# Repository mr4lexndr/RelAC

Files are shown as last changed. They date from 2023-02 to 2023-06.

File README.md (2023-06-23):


[][cc-by-nc-sa]

This work is licensed under a
[Creative Commons Attribution-NonCommercial-ShareAlike 4.0 International License][cc-by-nc-sa].

[][cc-by-nc-sa]



[cc-by-nc-sa]: http://creativecommons.org/licenses/by-nc-sa/4.0/
[cc-by-nc-sa-image]: https://licensebuttons.net/l/by-nc-sa/4.0/88x31.png
[cc-by-nc-sa-shield]: https://img.shields.io/badge/License-CC%20BY--NC--SA%204.0-lightgrey.svg
# RelAC

HomeKit 2-channel Relay module with mains Switch Input based on the [HomeSpan](https://github.com/HomeSpan/HomeSpan) library. It is mainly intended to be used with mains voltage appliances controlled in parallel with the Home app and physical switch. It could be hidden e.g. behind a wall light switch.

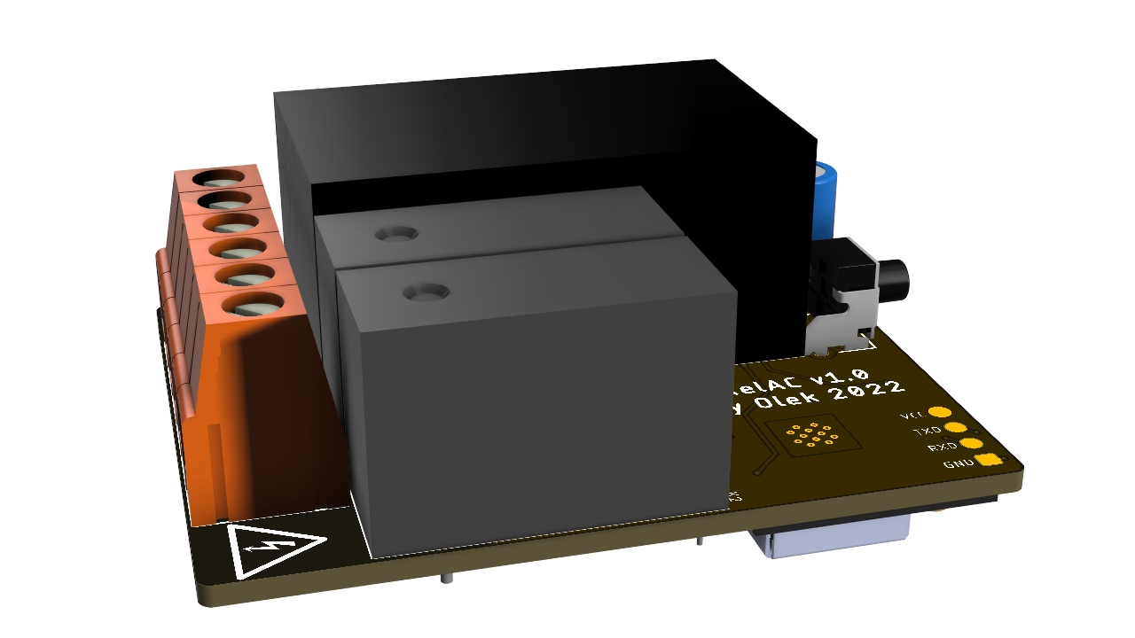
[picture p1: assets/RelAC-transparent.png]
RelAC


## Main Features
- Mains Supply 100-240 Vac
- Status LED and Control push button for easy configuration
- 2 latching relays for low power consumption and thermal emmisions
- 2 live inputs
- Small form factor to be hidden behind the wall light switch.
- Can be configured as single channel device to save cost
  
### Switching Relays
- High quality, low wear Panasonic ADW1203HLW  
- Switching Capacity 16A @ 277V AC  
- Contact material AgSnO2 to minimise arcing  

## User Integration with HomeSpan
Status LED and Control Button are attached to deafault pins for most of the boards. S1 Button is also used as boot button during programming
- LED `GPIO2`
- Button `GPIO0`

## Pinout
Pin assignment for relays and switch inputs. For single channel version only `RELAY 1` and `SWITCH 2` are used.

- RELAY 1
  -  on `GPIO27`
  - off `GPIO26`
- RELAY 2 
  - on `GPIO33`
  - off `GPIO32`
- MAINS INPUT
  - switch 1 `GPIO16`
  - switch 2 `GPIO13`

## User Guide
The setup procedure and configuration can be found [here](https://github.com/HomeSpan/HomeSpan/blob/master/docs/UserGuide.md)

## To Do

- [ ] finish 3D printed case
- [ ] reduce footprint with next revision
- [ ] change layout of programming pins and add RTS support

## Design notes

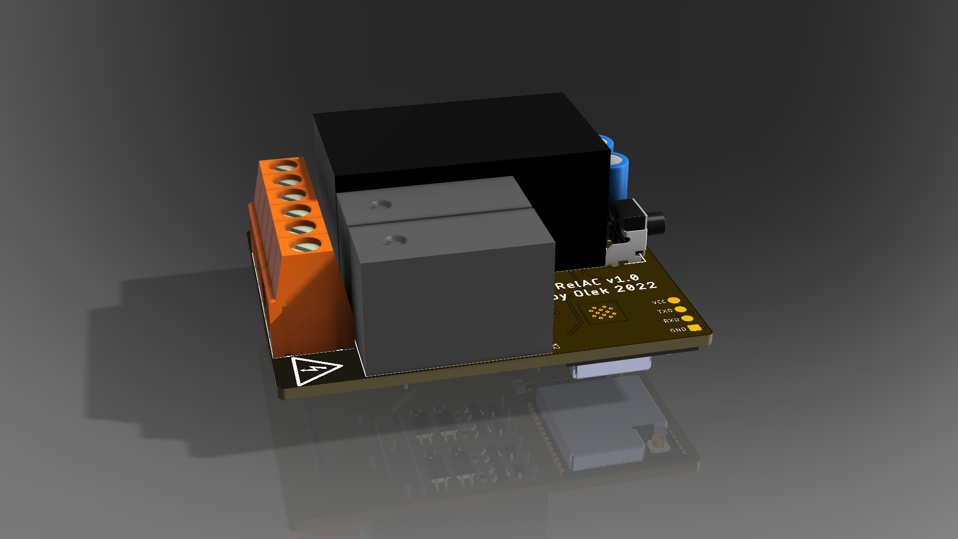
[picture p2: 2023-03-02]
assets/RelAC-board.png

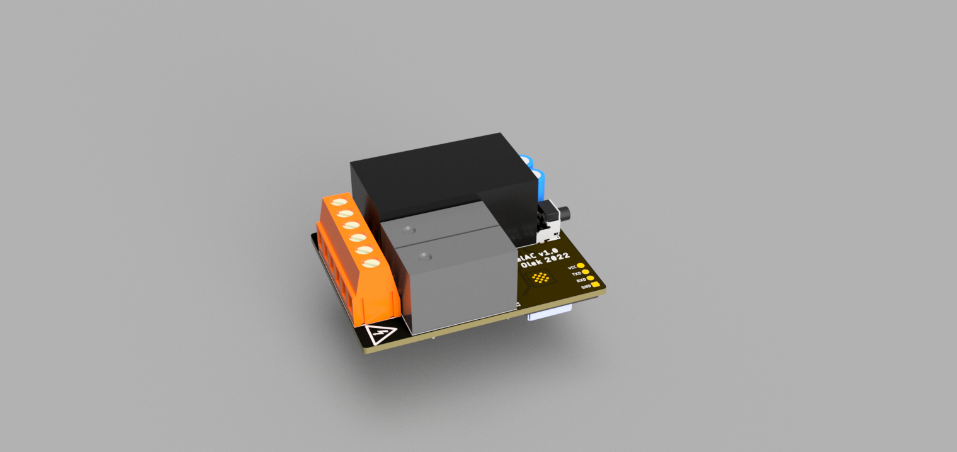
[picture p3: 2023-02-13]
assets/RelAC-top.png

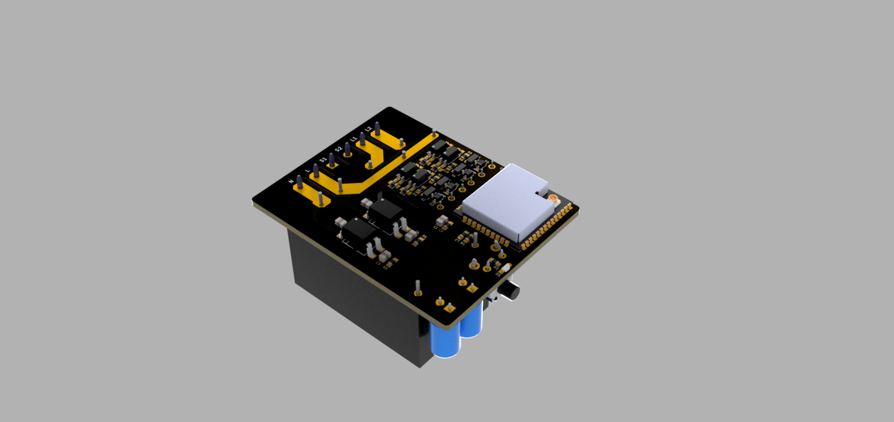
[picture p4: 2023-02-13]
assets/RelAC-bottom.png

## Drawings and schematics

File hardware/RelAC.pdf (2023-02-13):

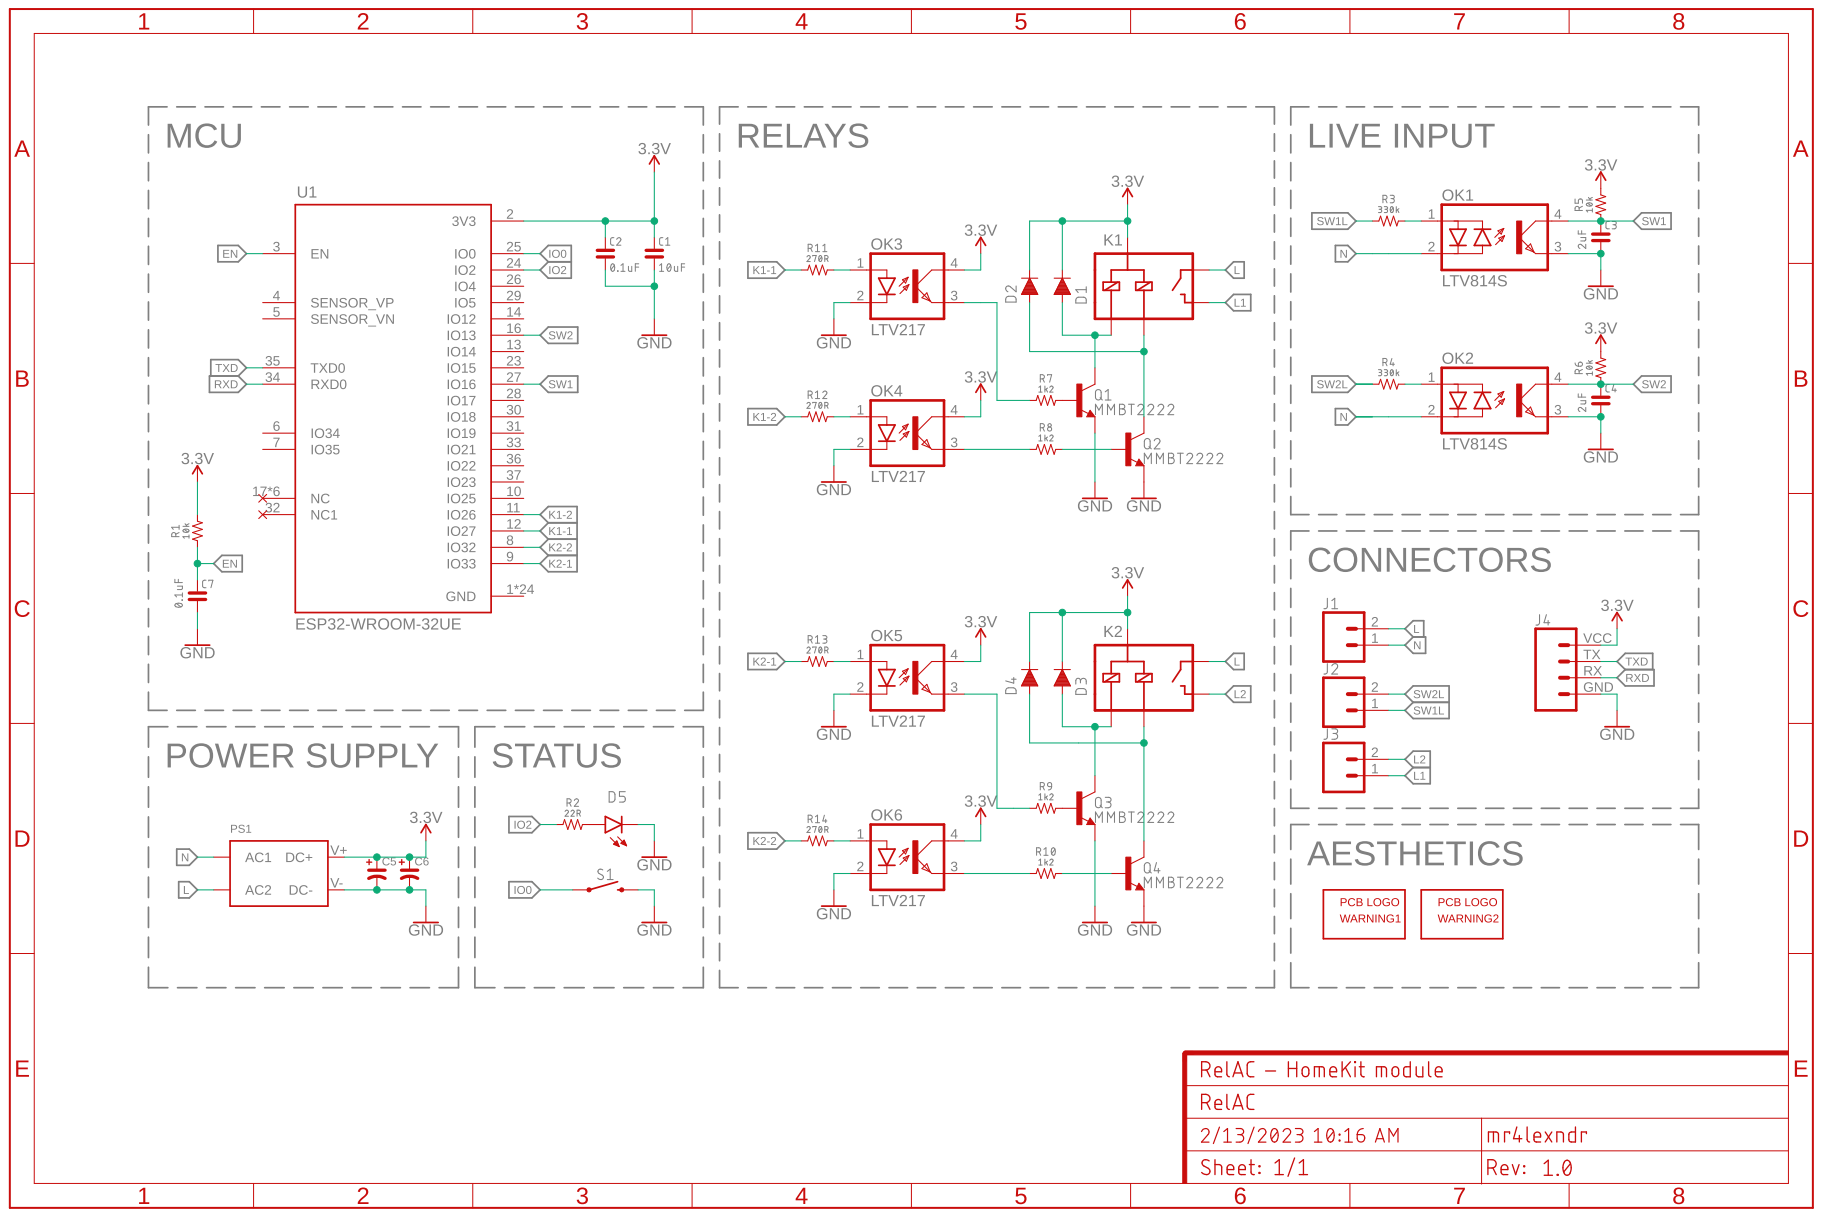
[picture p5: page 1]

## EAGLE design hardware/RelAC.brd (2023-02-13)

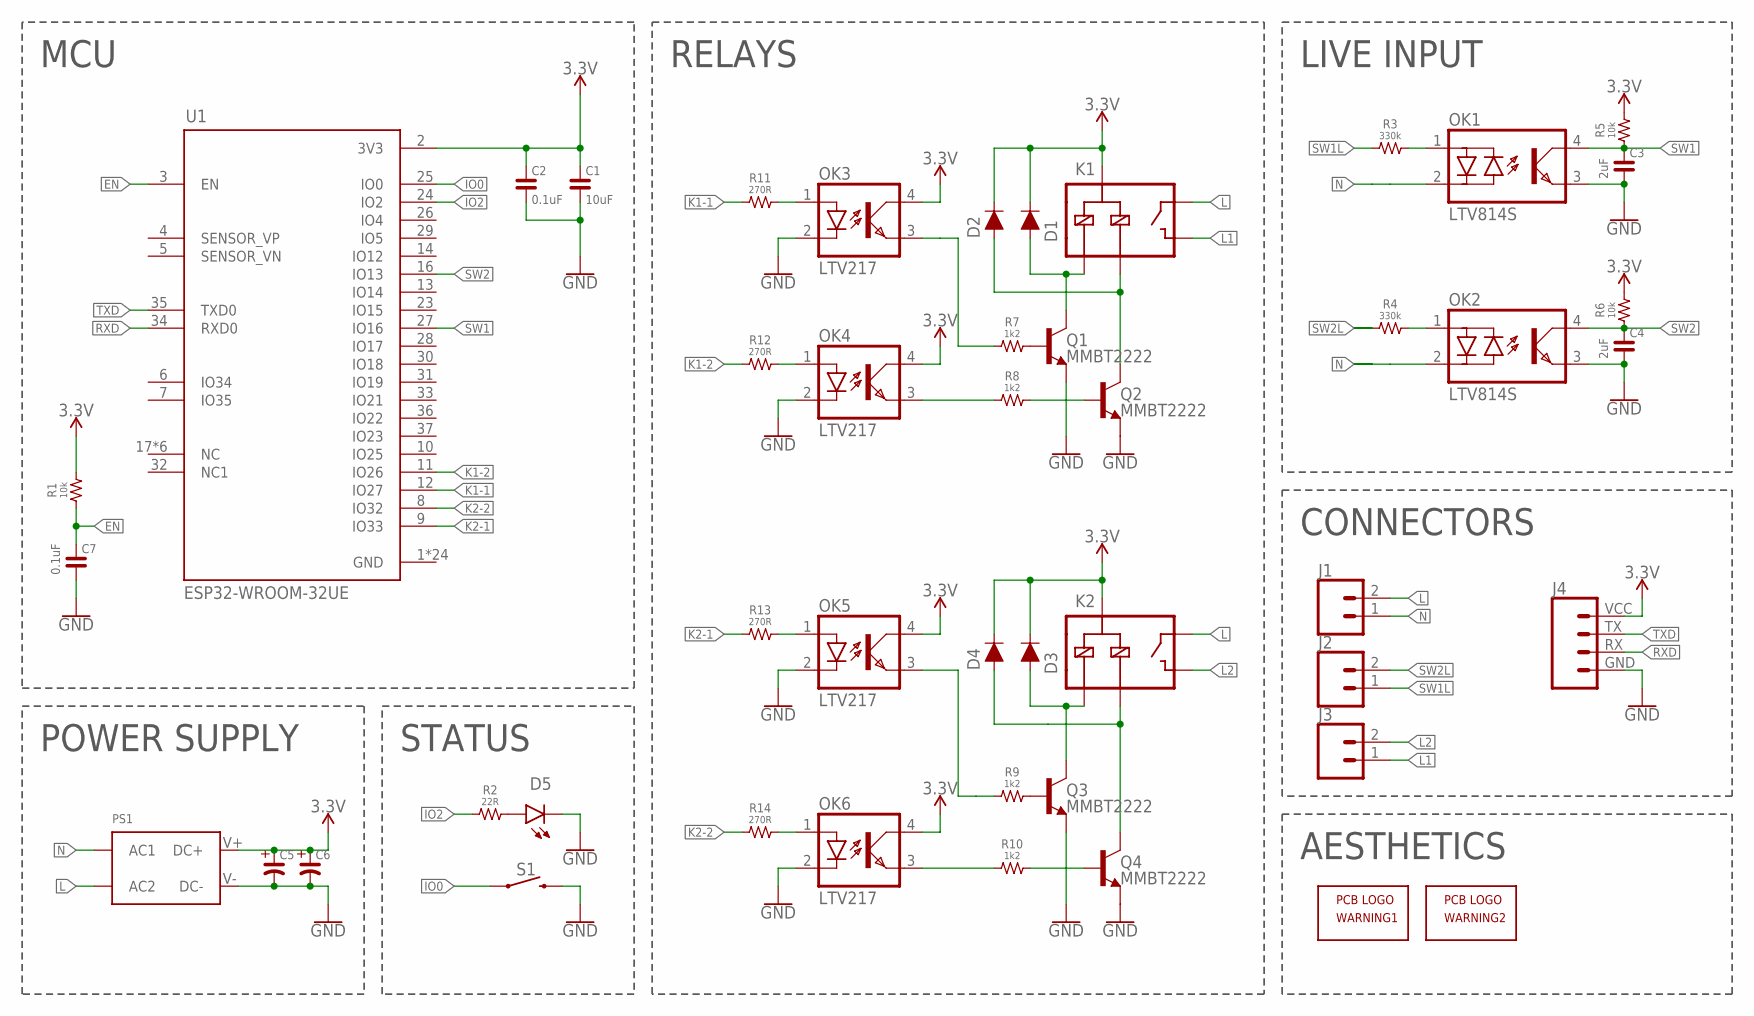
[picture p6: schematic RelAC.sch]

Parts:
C1: 10uF; 0805
C2, C7: 0.1uF; 0603
C3, C4: 2uF; 0805
C5, C6: CAP-POLAR-THT_2.5MM-W; CPOL-RADIAL-2.5MM-6.5MM
D1, D2, D3, D4: DIODE-SOD323; SOD-323
D5: LED-ANGLE-2MM
J1, J2, J3: CONN_02-5MM-SCREWTERMINAL; SCREWTERMINAL-5MM-2-DIBO
J4: CONN_04-UART-SMD; UART
K1, K2: RELAY-SPST-LATCHING; RELAY-PANASONIC-ADW1203HLW
OK1, OK2: LTV814S; DIL4-SMD-SMALL
OK3, OK4, OK5, OK6: LTV217; MINI-FLAT-4
PS1: POWER-SUPPLY-HI-LINK-5W; HI-LINK-POWER-SUPPLY
Q1, Q2, Q3, Q4: MMBT2222; SOT23-3
R1, R5, R6: 10k; 0603
R2: 22R; 0603
R3, R4: 330k; 0805
R7, R8, R9, R10: 1k2; 0603
R11, R12, R13, R14: 270R; 0603
S1: MOMENTARY-SWITCH-SPST-PTH-RIGHT-ANGLE-KIT; TACTILE_SWITCH_PTH_RIGHT_ANGLE_KIT
U1: ESP32-WROOM-32UE; MODULE_ESP32-WROOM-32UE(M113EH6400UH3Q0)
WARNING1, WARNING2: PCB-GRAPHICS-HIGH-VOLTAGE; HIGH-VOLTAGE

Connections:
3.3V: C1.2, C2.2, C5.+, C6.+, D1.C, D2.C, D3.C, D4.C, J4.VCC (4), K1.COILM (COIL-COM), K2.COILM (COIL-COM), OK3.4 (COL), OK4.4 (COL), OK5.4 (COL), OK6.4 (COL), PS1.V+ (DC+), R1.2, R5.2, R6.2, U1.2 (3V3)
EN: C7.2, R1.1, U1.3 (EN)
GND: C1.1, C2.1, C3.1, C4.1, C5.-, C6.-, C7.1, D5.C, J4.GND (1), OK1.3 (EMIT), OK2.3 (EMIT), OK3.2 (C), OK4.2 (C), OK5.2 (C), OK6.2 (C), PS1.V- (DC-), Q1.2 (E), Q2.2 (E), Q3.2 (E), Q4.2 (E), S1.2, U1.1 (GND), U1.15 (GND), U1.38 (GND), U1.39_1 (GND), U1.39_2 (GND), U1.39_3 (GND), U1.39_4 (GND), U1.39_5 (GND), U1.39_6 (GND), U1.39_7 (GND), U1.39_8 (GND), U1.39_9 (GND), U1.39_10 (GND), U1.39_11 (GND), U1.39_12 (GND), U1.39_13 (GND), U1.39_14 (GND), U1.39_15 (GND), U1.39_16 (GND), U1.39_17 (GND), U1.39_18 (GND), U1.39_19 (GND), U1.39_20 (GND), U1.39_21 (GND)
IO0: S1.1, U1.25 (IO0)
IO2: R2.1, U1.24 (IO2)
K1-1: R11.1, U1.12 (IO27)
K1-2: R12.1, U1.11 (IO26)
K2-1: R13.1, U1.9 (IO33)
K2-2: R14.1, U1.8 (IO32)
L: J1.2, K1.POLE, K2.POLE, PS1.AC2
L1: J3.1, K1.NO
L2: J3.2, K2.NO
N: J1.1, OK1.2 (C), OK2.2 (C), PS1.AC1
unnamed: D2.A, K1.COIL2, Q2.3 (C)
unnamed: D1.A, K1.COIL1, Q1.3 (C)
unnamed: OK1.1 (A), R3.2
unnamed: D5.A, R2.2
unnamed: OK2.1 (A), R4.2
unnamed: Q1.1 (B), R7.2
unnamed: Q2.1 (B), R8.2
unnamed: OK3.3 (EMIT), R7.1
unnamed: OK4.3 (EMIT), R8.1
unnamed: D3.A, K2.COIL1, Q3.3 (C)
unnamed: D4.A, K2.COIL2, Q4.3 (C)
unnamed: Q3.1 (B), R9.2
unnamed: Q4.1 (B), R10.2
unnamed: OK6.3 (EMIT), R10.1
unnamed: OK5.3 (EMIT), R9.1
unnamed: OK6.1 (A), R14.2
unnamed: OK5.1 (A), R13.2
unnamed: OK4.1 (A), R12.2
unnamed: OK3.1 (A), R11.2
RXD: J4.RX (2), U1.34 (RXD0)
SW1: C3.2, OK1.4 (COL), R5.1, U1.27 (IO16)
SW1L: J2.1, R3.1
SW2: C4.2, OK2.4 (COL), R6.1, U1.16 (IO13)
SW2L: J2.2, R4.1
TXD: J4.TX (3), U1.35 (TXD0)

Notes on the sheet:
MCU
RELAYS
LIVE INPUT
STATUS
POWER SUPPLY
CONNECTORS
AESTHETICS

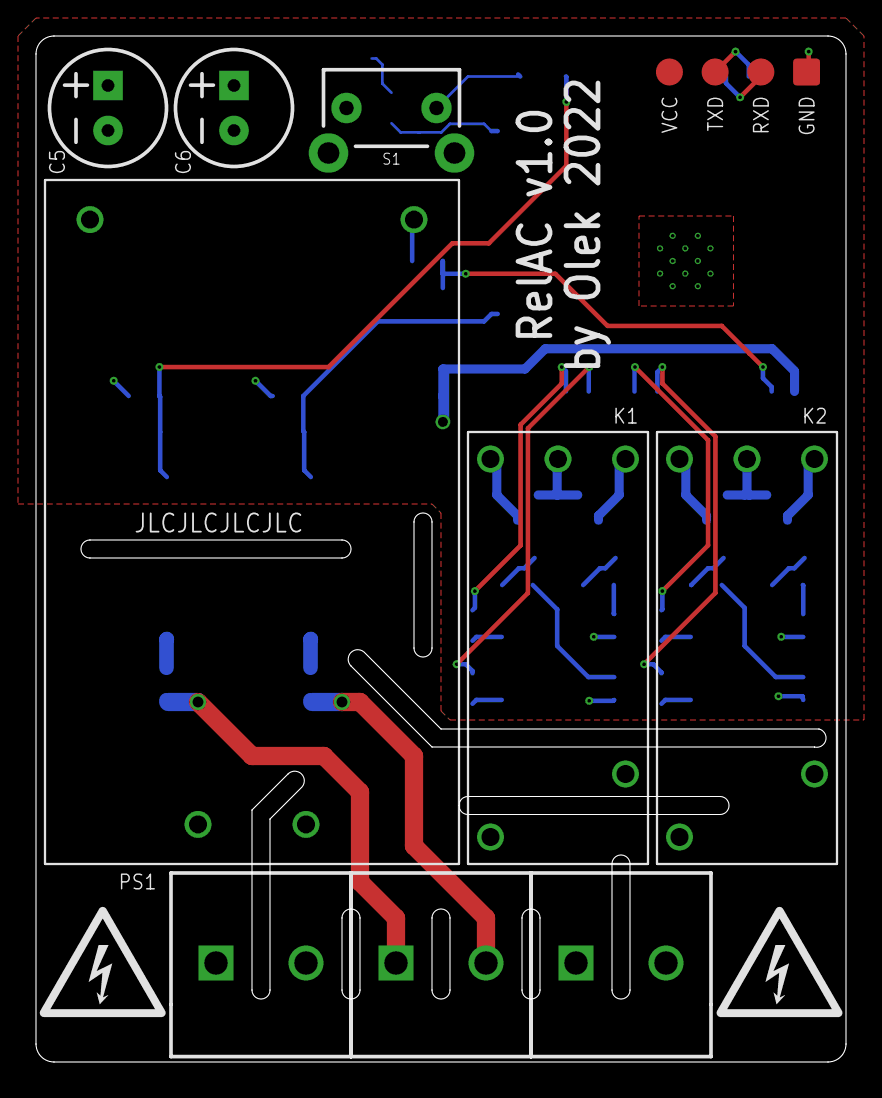
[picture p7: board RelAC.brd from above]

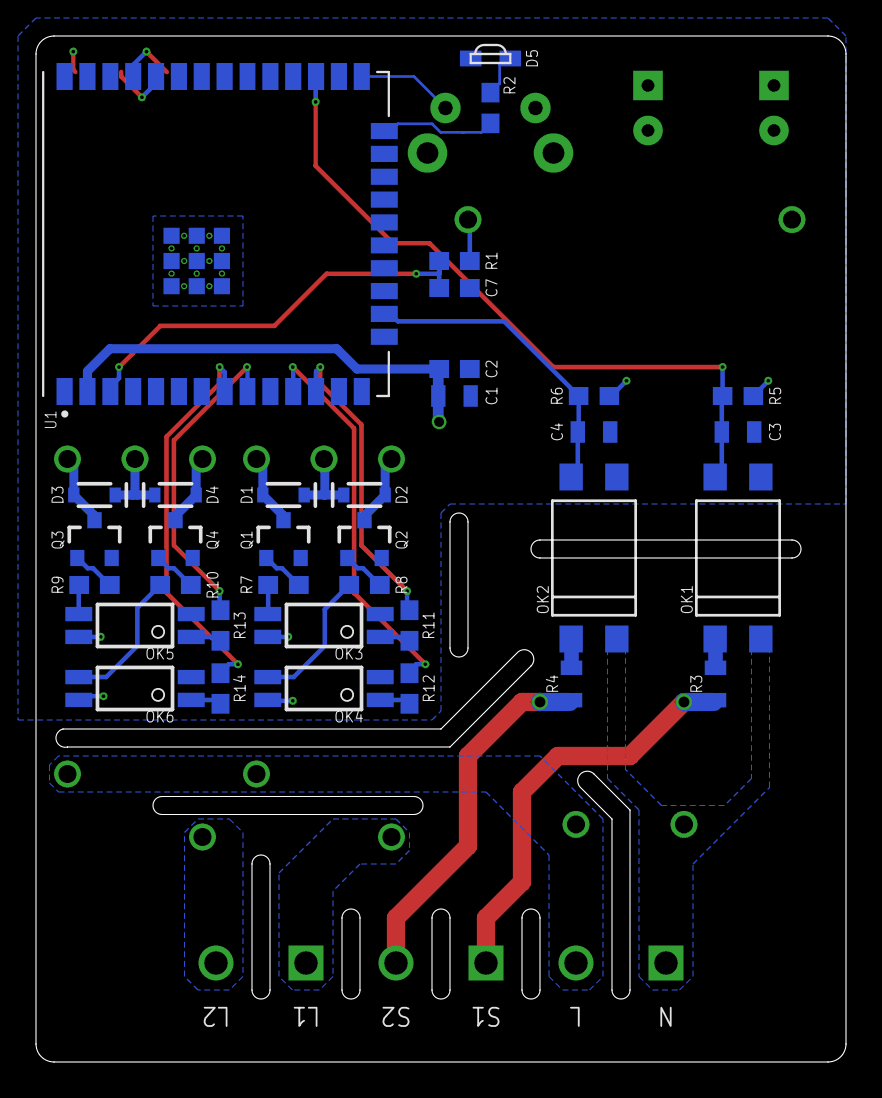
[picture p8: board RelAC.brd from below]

Board: 2 copper layers, 45.0 x 57.0 mm, 47 parts (35 on the bottom side), 38 nets.

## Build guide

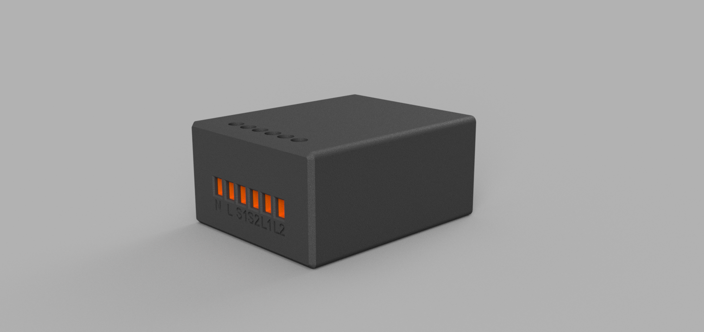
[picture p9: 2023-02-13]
assets/RelAC-dual-assembly.png

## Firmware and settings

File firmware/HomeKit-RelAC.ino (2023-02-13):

////////////////////////////////////////////////////////////
//                                                        //
//      RelAC: a HomeKit dual channel relay module        //
//       with live switch input based on HomeSpan         //
//    ----------------------------------------------      //
//                Made by mr4lexndr 2023                  //
//                 current hardware v1.0                  //
//                                                        //
////////////////////////////////////////////////////////////

/*
 * HARDWARE:
 * - ESP32-WROOM-32UE
 * - Panasonic ADW1203HLW relays 
 *    latching coil to minimise power consumption and thermal emmissions
 * 
 * PIN CONFIGURATION: 
 *  relay-1
 *    set coil    27
 *    reset coil  26
 *    
 *  relay-2
 *    set coil    33
 *    reset coil  32
 *    
 *  live inputs
 *    switch-1    16  
 *    switch-2    13
 * 
 */
 
#include "HomeSpan.h" 
#include "DEV_RELAY.h"          

void setup() {

 Serial.begin(115200);

 homeSpan.setStatusPin(2);    // onboard status LED pin
 homeSpan.setControlPin(0);   // pushbutton pin

 homeSpan.enableOTA();        // enable arduino OTA

 homeSpan.begin(Category::Switches,"RelAC by mr4lexndr","RelAC"); //CatID, Display Name, Hostname Base

 new SpanAccessory(); 
  
    new Service::AccessoryInformation();    
      new Characteristic::Name("Relay Module");    
      new Characteristic::Manufacturer("mr4lexndr"); 
      //new Characteristic::SerialNumber("SerialHere");  
      new Characteristic::Model("RelAC");   
      new Characteristic::FirmwareRevision("1.0");  
      new Characteristic::Identify();

      new Service::HAPProtocolInformation();          
      new Characteristic::Version("1.1.0");                                                       

      // dual channel version
      new DEV_RELAY(27,26,16);  //device1 PINS(on, off, live input)
      new DEV_RELAY(33,32,13);  //device2 PINS(on, off, live input)
      
      // single channel version
      // new DEV_RELAY(27,26,13);  //PINS on, off, input
      
} // end of setup()

void loop(){
  
  homeSpan.poll();
  
} // end of loop()

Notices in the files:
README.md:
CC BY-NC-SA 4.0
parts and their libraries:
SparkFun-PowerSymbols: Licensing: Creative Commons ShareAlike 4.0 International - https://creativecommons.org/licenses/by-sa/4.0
